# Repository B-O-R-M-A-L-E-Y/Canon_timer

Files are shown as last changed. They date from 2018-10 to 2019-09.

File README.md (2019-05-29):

# Canon_timer/Пульт Timelapse съёмки (для фотоаппартов Canon)
Можно настроить интервал между снимками, их количество и выдержку. Файлы печатной платы и схемы в папке timr_canon_pcb (проект в KiCAD). Исходный код в папке Src, имеется также иницализация CubeMX и проект в Keil. Применена библиотека HAL.
### Небольшая инструкция
 - При запуске фотоаппарат необходимо перевести в режим BULB.
 - Подключить пульт (разъем jack 2.5)
 - Настройка параметров осуществляется выбором соответствующего пункта меню. Затем нужно нажать на энкодер, вращением энкодера изменяется численное значение парметра. Для перехода к следующему значению нужно снова нажать на энкодер.
 - Для запуска перейти в пункт Start и нажать на энкодер. Для выхода из этого режима нажать на энкодер в течении 5 сек.

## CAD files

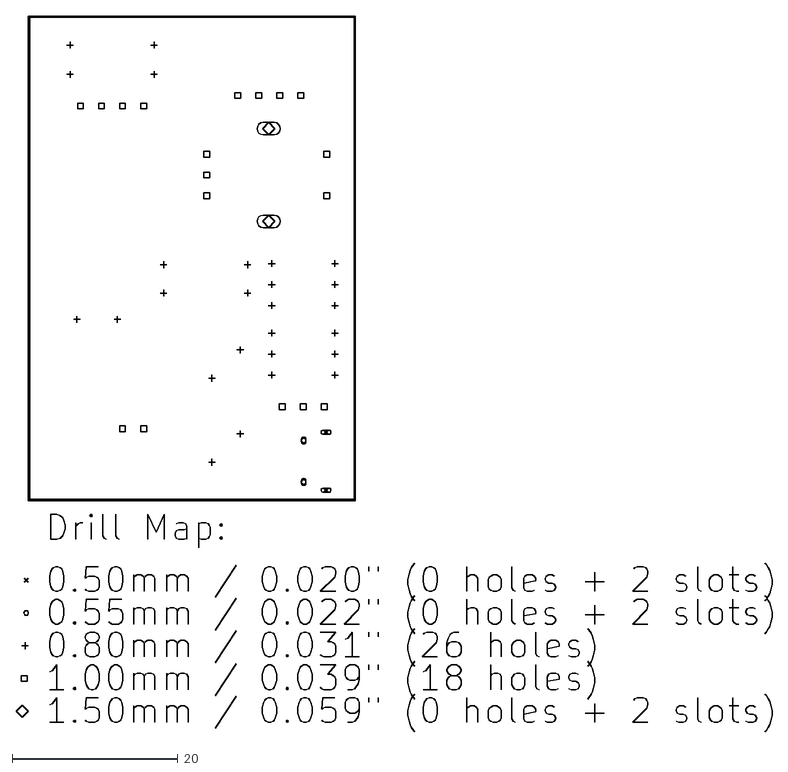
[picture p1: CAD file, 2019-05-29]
timr_canon_pcb/timer-drl_map.dxf
91.4 x 86.5

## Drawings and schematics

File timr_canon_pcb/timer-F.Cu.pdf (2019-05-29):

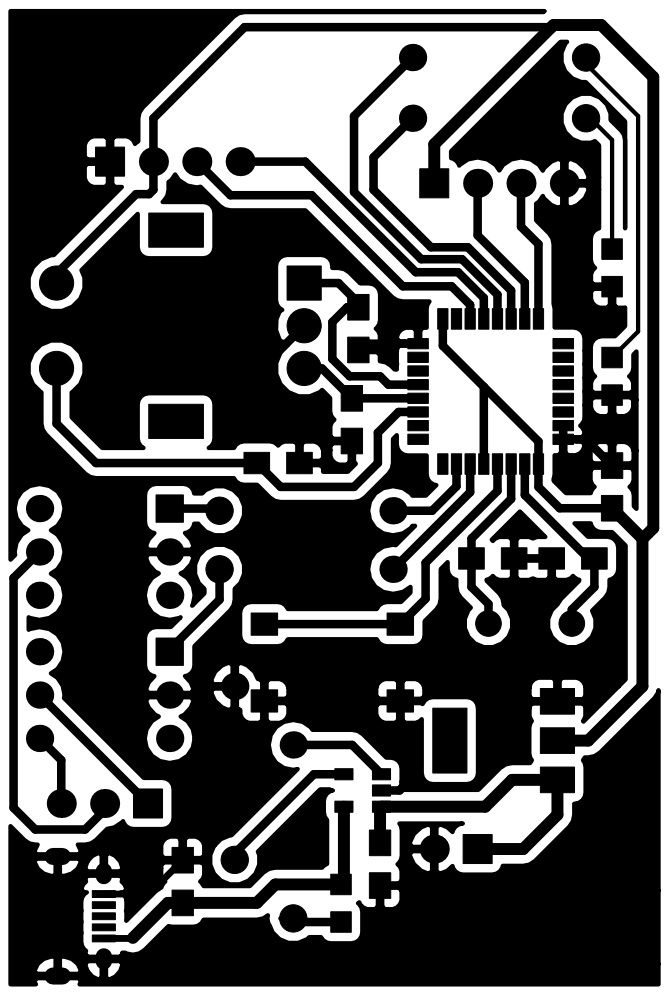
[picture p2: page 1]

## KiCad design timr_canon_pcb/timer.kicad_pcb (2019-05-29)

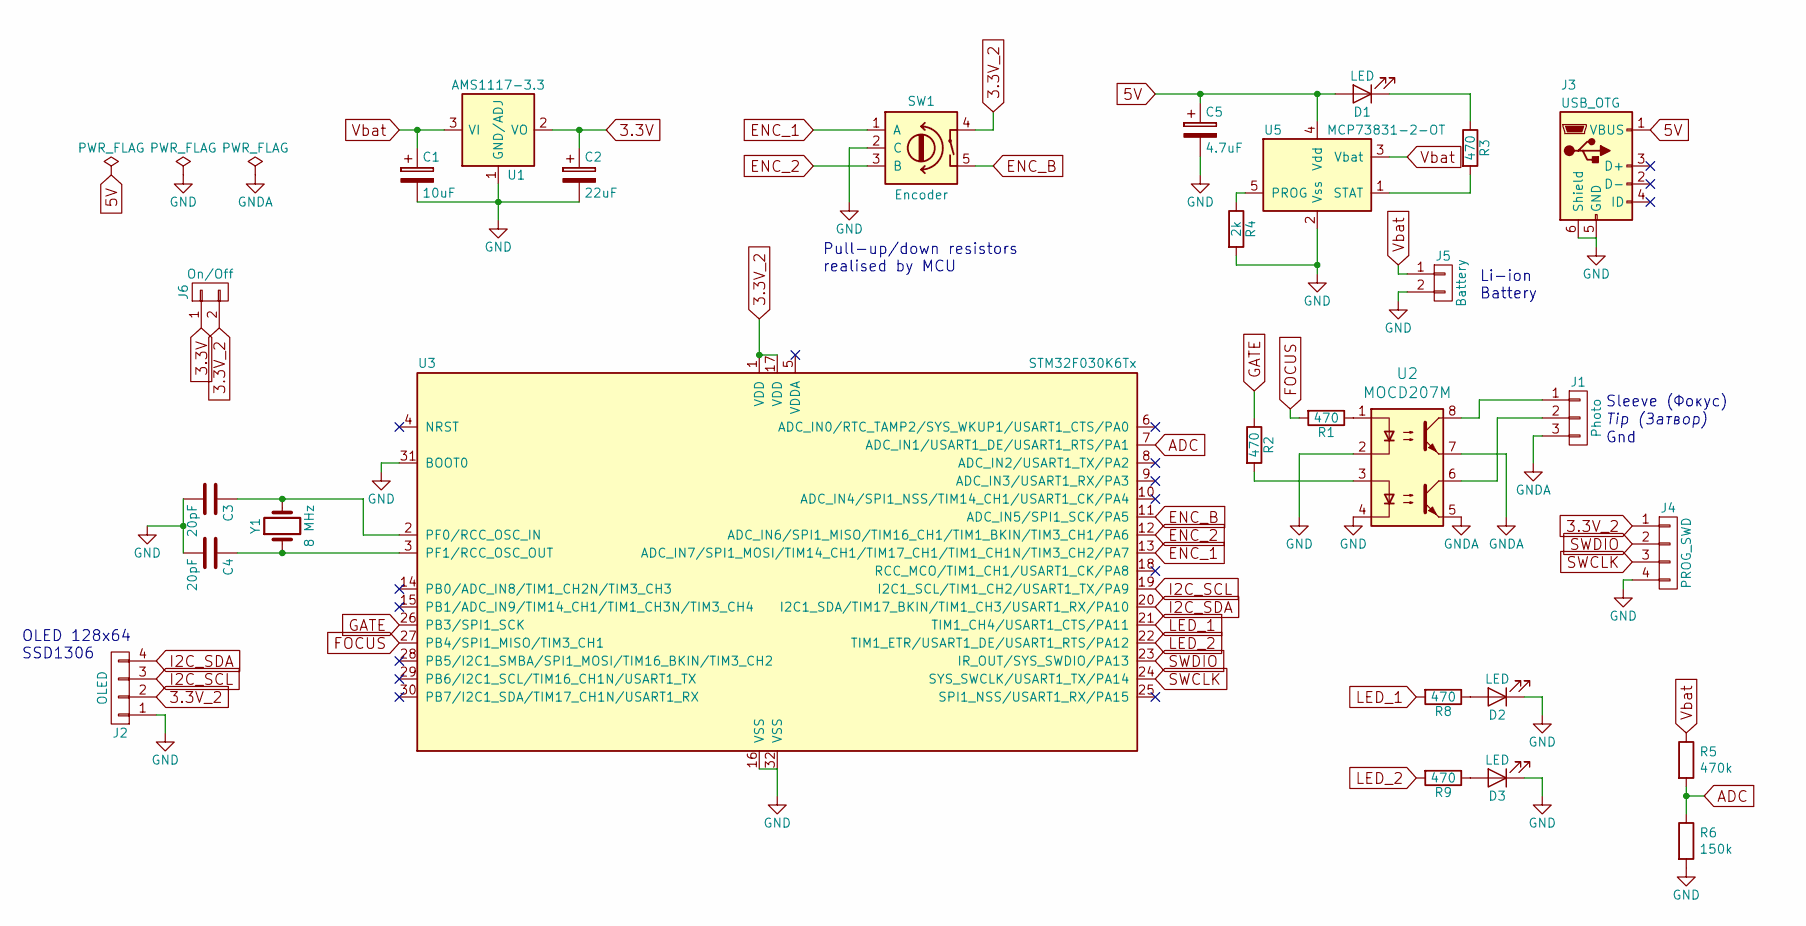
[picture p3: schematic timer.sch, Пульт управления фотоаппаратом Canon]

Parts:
C1: 10uF; C_0805_HandSoldering
C2: 22uF; C_0805_HandSoldering
C3, C4: 20pF; C_0805_HandSoldering
C5: 4.7uF; C_0805_HandSoldering
D1, D2, D3: LED; LED_0805
J1: Photo; Pin_Header_Straight_1x03_Pitch2.54mm
J2: OLED; Pin_Header_Straight_1x04_Pitch2.54mm
J3: USB_OTG; USB_Micro-B
J4: PROG_SWD; Pin_Header_Straight_1x04_Pitch2.54mm
J5: Battery; Pin_Header_Straight_1x02_Pitch2.54mm
J6: On/Off; Pin_Header_Straight_1x02_Pitch2.54mm
R1, R2, R3, R8, R9: 470; R_0805_2012Metric_Pad1.15x1.40mm_HandSolder
R4: 2k; R_0805_2012Metric_Pad1.15x1.40mm_HandSolder
R5: 470k; R_0805_2012Metric_Pad1.15x1.40mm_HandSolder
R6: 150k; R_0805_2012Metric_Pad1.15x1.40mm_HandSolder
SW1: Encoder; RotaryEncoder_Alps_EC11E-Switch_Vertical_H20mm
U1: AMS1117-3.3; SOT-223
U2: MOCD207M; SOIC-8_3.9x4.9mm_P1.27mm
U3: STM32F030K6Tx; LQFP-32_7x7mm_Pitch0.8mm
U5: MCP73831-2-OT; SOT-23-5
Y1: 8 MHz; Crystal_HC49-4H_Vertical

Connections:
3.3V: C2.1, J6.1, U1.2 (VO)
3.3V_2: J2.2, J4.1, J6.2, SW1.4, U3.1 (VDD), U3.17 (VDD)
5V: C5.1, D1.2 (A), J3.1 (VBUS), U5.4 (Vdd)
ADC: R5.2, R6.1, U3.7 (ADC_IN1/USART1_DE/USART1_RTS/PA1)
ENC_1: SW1.1 (A), U3.13 (ADC_IN7/SPI1_MOSI/TIM14_CH1/TIM17_CH1/T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)
ENC_2: SW1.3 (B), U3.12 (ADC_IN6/SPI1_MISO/TIM16_CH1/TIM1_BKIN/T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)
ENC_B: SW1.5, U3.11 (ADC_IN5/SPI1_SCK/PA5)
FOCUS: R1.2, U3.27 (PB4/SPI1_MISO/TIM3_CH1)
GATE: R2.1, U3.26 (PB3/SPI1_SCK)
GND: C1.2, C2.2, C3.2, C4.2, C5.2, D2.1 (K), D3.1 (K), J2.1, J3.5 (GND), J3.6 (Shield), J4.4, J5.2, R4.2, R6.2, SW1.2 (C), U1.1 (GND/ADJ), U2.2, U2.4, U3.16 (VSS), U3.31 (BOOT0), U3.32 (VSS), U5.2 (Vss)
GNDA: J1.3, U2.5, U2.7
I2C_SCL: J2.3, U3.19 (I2C1_SCL/TIM1_CH2/USART1_TX/PA9)
I2C_SDA: J2.4, U3.20 (I2C1_SDA/TIM17_BKIN/TIM1_CH3/USART1_RX/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)
LED_1: R8.2, U3.21 (TIM1_CH4/USART1_CTS/PA11)
LED_2: R9.2, U3.22 (TIM1_ETR/USART1_DE/USART1_RTS/PA12)
unnamed: C3.1, U3.2 (PF0/RCC_OSC_IN), Y1.2
unnamed: C4.1, U3.3 (PF1/RCC_OSC_OUT), Y1.1
unnamed: D1.1 (K), R3.1
unnamed: D2.2 (A), R8.1
unnamed: D3.2 (A), R9.1
unnamed: J1.1, U2.8
unnamed: J1.2, U2.6
unnamed: R1.1, U2.1
unnamed: R2.2, U2.3
unnamed: R3.2, U5.1 (STAT)
unnamed: R4.1, U5.5 (PROG)
SWCLK: J4.3, U3.24 (SYS_SWCLK/USART1_TX/PA14)
SWDIO: J4.2, U3.23 (IR_OUT/SYS_SWDIO/PA13)
Vbat: C1.1, J5.1, R5.1, U1.3 (VI), U5.3 (Vbat)

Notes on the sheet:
Tip (Затвор)
Sleeve (Фокус)
Gnd
OLED 128x64 SSD1306
Li-ion Battery
Pull-up/down resistors realised by MCU

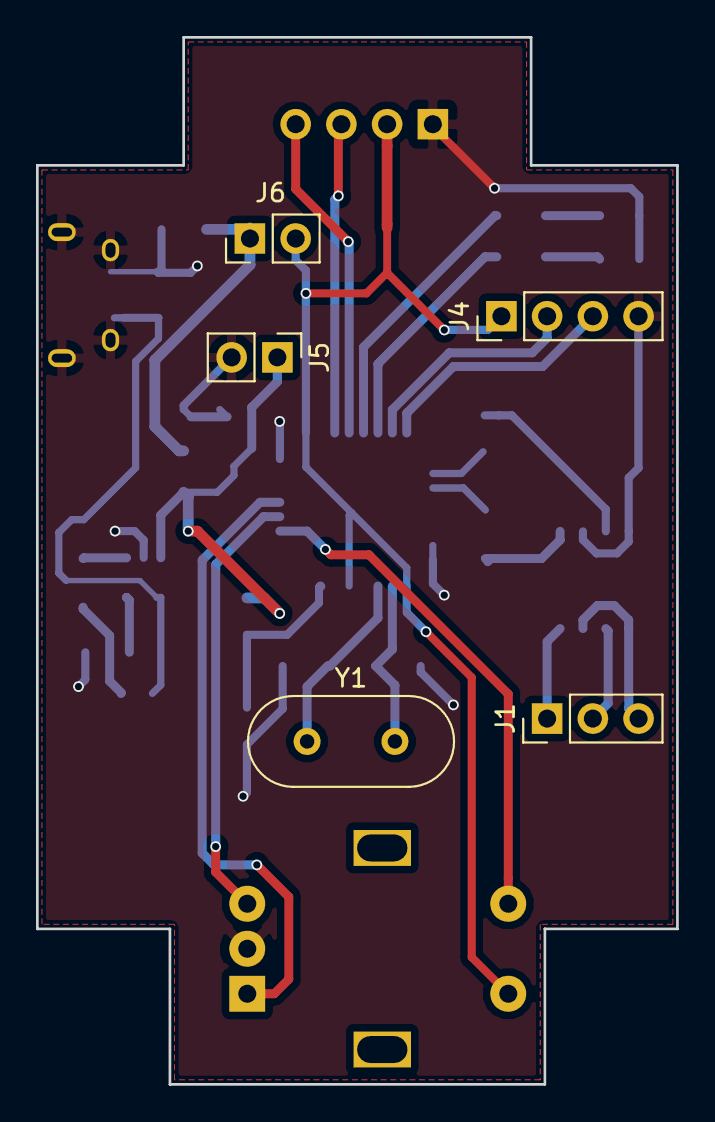
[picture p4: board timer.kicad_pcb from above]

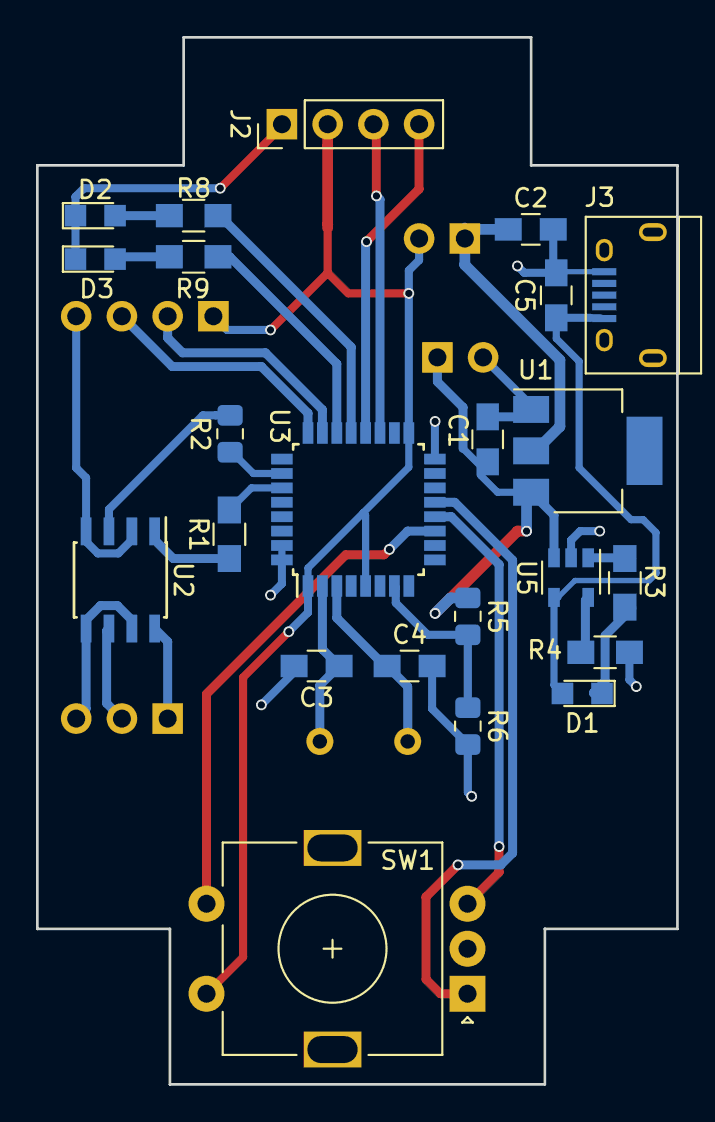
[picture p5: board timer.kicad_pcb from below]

Board: 2 copper layers, 35.6 x 58.2 mm, 28 parts (23 on the bottom side), 29 nets.

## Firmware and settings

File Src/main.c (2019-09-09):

/**
  ******************************************************************************
  * @file           : main.c
  * @brief          : Main program body
  ******************************************************************************
  ** This notice applies to any and all portions of this file
  * that are not between comment pairs USER CODE BEGIN and
  * USER CODE END. Other portions of this file, whether
  * inserted by the user or by software development tools
  * are owned by their respective copyright owners.
  *
  * COPYRIGHT(c) 2018 STMicroelectronics
  *
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
  ******************************************************************************
  */
/* Includes ------------------------------------------------------------------*/
#include "main.h"
#include "stm32f0xx_hal.h"

/* USER CODE BEGIN Includes */
#include "ssd1306.h"
#include "stdlib.h"
#include "string.h"
/* USER CODE END Includes */

I2C_HandleTypeDef hi2c1;

IWDG_HandleTypeDef hiwdg;

TIM_HandleTypeDef htim3;
TIM_HandleTypeDef htim14;
TIM_HandleTypeDef htim16;
TIM_HandleTypeDef htim17;

ADC_HandleTypeDef hadc;

/* USER CODE BEGIN PV */
/* --------------------------- Private variables -----------------------------*/

AUTOMATE_STATES current_state = menu_navigation;
CURSOR_STATES current_cursor = exposition;

// Exposition parameters
uint16_t set_exp_minutes = 0, set_exp_sec = 3;
uint16_t tmp_exp_minutes, tmp_exp_sec;
// Number of shots
uint16_t set_num_shots = 3, tmp_num_shots;
// Interval paramters
uint16_t set_int_minutes = 0, set_int_sec = 5;
uint16_t tmp_int_minutes, tmp_int_sec;



uint8_t update_screen_flag = 0, gate_flag = 0, exiting_run = 0;

uint32_t seconds_counter = 0;

char *Menu_Items[]={"Exp:               ",
                    "Num:               ",
                    "Int:               ",
                    "Start              "};

char buffer[5];
/* USER CODE END PV */

void SystemClock_Config(void);
static void MX_GPIO_Init(void);
static void MX_I2C1_Init(void);
static void MX_TIM3_Init(void);
//static void MX_IWDG_Init(void);
static void MX_TIM14_Init(void);
static void MX_TIM16_Init(void);
static void MX_TIM17_Init(void);
static void MX_ADC_Init(void);

/* USER CODE BEGIN PFP */
/* ---------------------------- Private function prototypes ------------------*/

void reverse(char s[]);
void itoa(int n, char s[]);

void Menu(void);
void Convert_time(uint16_t* minutes, uint16_t* seconds);

/* USER CODE END PFP */

/**
  * @brief  The application entry point.
  *
  * @retval None
  */
int main(void)
{
  /* MCU Configuration----------------------------------------------------------*/

  /* Reset of all peripherals, Initializes the Flash interface and the Systick. */
  HAL_Init();

  /* Configure the system clock */
  SystemClock_Config();

  /* Initialize all configured peripherals */
  MX_GPIO_Init();
	MX_ADC_Init();
	HAL_Delay(300);
  MX_I2C1_Init();
  MX_TIM3_Init();
  //MX_IWDG_Init();
  MX_TIM14_Init();
  MX_TIM16_Init();
  MX_TIM17_Init();
  /* USER CODE BEGIN 2 */
	current_state = menu_navigation;
  HAL_TIM_Encoder_Start(&htim3, TIM_CHANNEL_ALL);
  HAL_NVIC_SetPriority(TIM3_IRQn, 0, 0);
  HAL_NVIC_EnableIRQ(TIM3_IRQn);
  HAL_TIM_Base_Start_IT(&htim3);


  // Seconds Counter startup duty
  HAL_TIM_Base_Start_IT(&htim14);
  HAL_TIM_Base_Stop_IT(&htim14);
  HAL_TIM_Base_Start_IT(&htim16);
	HAL_ADC_Start(&hadc);

  HAL_TIM_Base_Start_IT(&htim17);

  HAL_GPIO_WritePin(GPIOA, LED_RED_PIN, GPIO_PIN_RESET);
  ssd1306_Init();
  current_cursor = exposition;
  /* USER CODE END 2 */

  /* Infinite loop */
  /* USER CODE BEGIN WHILE */
  while (1)
  {
  /* USER CODE END WHILE */

  /* USER CODE BEGIN 3 */
    //HAL_IWDG_Refresh(&hiwdg);

    if(__HAL_RCC_GET_SYSCLK_SOURCE() == RCC_SYSCLKSOURCE_STATUS_PLLCLK) HAL_GPIO_WritePin(GPIOA, LED_GREEN_PIN, GPIO_PIN_SET);
    else HAL_GPIO_WritePin(GPIOA, LED_GREEN_PIN, GPIO_PIN_RESET);

    if (update_screen_flag)
    {
      ssd1306_Fill(Black);
      ssd1306_UpdateScreen();
      update_screen_flag = 0;
    }
		
    if (seconds_counter > STOP_TIME_SEC) //if more than 10 s need to stop
    {
			/*
      // Entering STOP Mode Procedure
      seconds_counter = 0;

      GPIO_InitTypeDef GPIO_InitStruct;
      

      ssd1306_WriteCommand(0xAE);       // OLED Off

      GPIO_InitStruct.Pin = ENC_BUTTON_PIN;
      GPIO_InitStruct.Mode = GPIO_MODE_EVT_RISING_FALLING;
      GPIO_InitStruct.Pull = GPIO_PULLDOWN;
      GPIO_InitStruct.Speed = GPIO_SPEED_FREQ_LOW;
      HAL_GPIO_Init(GPIOA, &GPIO_InitStruct);

      HAL_NVIC_SetPriority(EXTI4_15_IRQn, 0, 0);
      HAL_NVIC_EnableIRQ(EXTI4_15_IRQn);

      HAL_GPIO_WritePin(GPIOA, LED_GREEN_PIN|LED_RED_PIN, GPIO_PIN_RESET);
      HAL_GPIO_WritePin(GPIOB, GATE_PIN|FOCUS_PIN, GPIO_PIN_RESET);

      HAL_PWR_EnterSTOPMode(PWR_LOWPOWERREGULATOR_ON, PWR_STOPENTRY_WFE);

      // Exit from STOP Mode procedure
      SystemClock_Config();
      ssd1306_WriteCommand(0xAF);      // OLED On

      GPIO_InitStruct.Pin = ENC_BUTTON_PIN;
      GPIO_InitStruct.Mode = GPIO_MODE_INPUT;
      GPIO_InitStruct.Pull = GPIO_PULLDOWN;
      HAL_GPIO_Init(GPIOA, &GPIO_InitStruct);
      
      // Need Delay to avoid going in interrupt
      HAL_NVIC_DisableIRQ(TIM3_IRQn);
      HAL_Delay(800);
      HAL_NVIC_EnableIRQ(TIM3_IRQn);
      
      current_state = menu_navigation;
			*/
			
    }

    Menu();
    
    if (current_state == running_timer || current_state == running_interval)
    {
      if(gate_flag)
      {
        // Reset Gate & Focus
        HAL_GPIO_WritePin(GPIOB, FOCUS_PIN|GATE_PIN, GPIO_PIN_RESET);
        HAL_TIM_Base_Stop_IT(&htim14);
        HAL_Delay(500);
        __HAL_TIM_SET_COUNTER(&htim14, 0);
        HAL_TIM_Base_Start_IT(&htim14);
        gate_flag = 0;
        // If not last shot, go to Interval state
        if(tmp_num_shots != 0)
        {
          tmp_int_minutes = set_int_minutes;
          tmp_int_sec = set_int_sec;
          tmp_exp_minutes = set_exp_minutes;
          tmp_exp_sec = set_exp_sec;
          current_state = running_interval;
          HAL_GPIO_WritePin(GPIOA, LED_RED_PIN,GPIO_PIN_RESET); // 1s LED Off
        }
        else
        {
          HAL_TIM_Base_Stop_IT(&htim14);
          __HAL_TIM_SET_COUNTER(&htim14, 0);
          HAL_GPIO_WritePin(GPIOA, LED_RED_PIN,GPIO_PIN_RESET); // 1s LED Off
          tmp_exp_minutes = set_exp_minutes;
          tmp_exp_sec = set_exp_sec;
          current_state = menu_navigation;
          update_screen_flag = 1;
        }
      }
    }
      
    if (exiting_run)
    {
      HAL_TIM_Base_Stop_IT(&htim16);
      HAL_Delay(1000);
      exiting_run = 0;
      HAL_TIM_Base_Start_IT(&htim16);
      HAL_GPIO_WritePin(GPIOB, FOCUS_PIN|GATE_PIN, GPIO_PIN_RESET);
    }   
  }
  /* USER CODE END 3 */

}

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
/* USER CODE BEGIN 4 */

// Reverse string
void reverse(char s[])
{
  int i, j;
  char c;

  for (i = 0, j = strlen(s)-1; i<j; i++, j--)
  {
    c = s[i];
    s[i] = s[j];
    s[j] = c;
  }
}

// Convert number n into char[] s
void itoa(int n, char s[])
{
  int i, sign;

  if ((sign = n) < 0)  /* записываем знак */
    n = -n;          /* делаем n положительным числом */
  i = 0;
  do {       /* генерируем цифры в обратном порядке */
    s[i++] = n % 10 + '0';   /* берем следующую цифру */
  } while ((n /= 10) > 0);     /* удаляем */
  if (sign < 0)
    s[i++] = '-';
  s[i] = '\0';
  reverse(s);
}

// Generate and update menu
void Menu(void)
{
  if (current_state != running_timer && current_state != running_interval)
  {
    for (int i=0; i<NUMBER_OF_MENU_ITEMS; i++)
    {
      ssd1306_SetCursor(0, i*FONT_HEIGHT);
      if(current_cursor == i) ssd1306_WriteString("->", Font_7x10, White);
      ssd1306_WriteString(Menu_Items[i], Font_7x10, White);
      switch (i)
      {
        case exposition:
          ssd1306_SetCursor(FONT_WIDTH*INDENT, i*FONT_HEIGHT);
          itoa(set_exp_minutes, buffer);
          ssd1306_WriteString(buffer, Font_7x10, White);
          ssd1306_WriteString("`  ", Font_7x10, White);
          itoa(set_exp_sec, buffer);
          ssd1306_WriteString(buffer, Font_7x10, White);
          ssd1306_WriteString("``", Font_7x10, White);
          break;
        case number:
          ssd1306_SetCursor(FONT_WIDTH*INDENT, i*FONT_HEIGHT);
          itoa(set_num_shots, buffer);
          ssd1306_WriteString(buffer, Font_7x10, White);
          break;
        case interval:
          ssd1306_SetCursor(FONT_WIDTH*INDENT, i*FONT_HEIGHT);
          itoa(set_int_minutes, buffer);
          ssd1306_WriteString(buffer, Font_7x10, White);
          ssd1306_WriteString("`  ", Font_7x10, White);
          itoa(set_int_sec, buffer);
          ssd1306_WriteString(buffer, Font_7x10, White);
          ssd1306_WriteString("``", Font_7x10, White);
          break;
        case start:
          break;
      }
    }
		/*
		itoa(p, buffer);
		ssd1306_SetCursor(0, 40);
		ssd1306_WriteString("Charge:    %", Font_7x10, White);
		ssd1306_SetCursor(8*FONT_WIDTH, 40);
		ssd1306_WriteString(buffer, Font_7x10, White);
		*/
  }
  else
  {
    for (int i=0; i<NUMBER_OF_MENU_ITEMS-1; i++)
    {
      ssd1306_SetCursor(0, i*FONT_HEIGHT);
      ssd1306_WriteString(Menu_Items[i], Font_7x10, White);
      switch (i)
      {
        case exposition:
          ssd1306_SetCursor(FONT_WIDTH*INDENT, i*FONT_HEIGHT);
          itoa(tmp_exp_minutes, buffer);
          ssd1306_WriteString(buffer, Font_7x10, White);
          ssd1306_WriteString("`  ", Font_7x10, White);
          itoa(tmp_exp_sec, buffer);
          ssd1306_WriteString(buffer, Font_7x10, White);
          ssd1306_WriteString("``", Font_7x10, White);
          break;
        case number:
          ssd1306_SetCursor(FONT_WIDTH*INDENT, i*FONT_HEIGHT);
          itoa(tmp_num_shots, buffer);
          ssd1306_WriteString(buffer, Font_7x10, White);
          break;
        case interval:
          ssd1306_SetCursor(FONT_WIDTH*INDENT, i*FONT_HEIGHT);
          itoa(tmp_int_minutes, buffer);
          ssd1306_WriteString(buffer, Font_7x10, White);
          ssd1306_WriteString("`  ", Font_7x10, White);
          itoa(tmp_int_sec, buffer);
          ssd1306_WriteString(buffer, Font_7x10, White);
          ssd1306_WriteString("``", Font_7x10, White);
          break;
        case start:
          break;
      }
    }
		/*
		itoa(p, buffer);
		ssd1306_SetCursor(0, 30);
		ssd1306_WriteString("Charge:    %", Font_7x10, White);
		ssd1306_SetCursor(8*FONT_WIDTH, 30);
		ssd1306_WriteString(buffer, Font_7x10, White);
		*/
    ssd1306_SetCursor(0, NUMBER_OF_MENU_ITEMS*FONT_HEIGHT);
    ssd1306_WriteString("     Running      ", Font_7x10, White);
  }
  ssd1306_UpdateScreen();
}


void Convert_time(uint16_t* minutes, uint16_t* seconds)
{
  if (*seconds >= 60)
  {
    uint16_t tmp_min;
    tmp_min = (*seconds)/60;
    *minutes = *minutes+tmp_min;
    *seconds = *seconds-tmp_min*60;
  }
}

/* USER CODE END 4 */
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


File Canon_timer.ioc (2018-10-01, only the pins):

Mcu.UserName=STM32F030K6Tx
PA0.Signal=GPIO_Output
PA1.Signal=GPIO_Output
PA10.Signal=I2C1_SDA
PA11.Signal=GPIO_Output
PA12.Signal=GPIO_Output
PA13.Signal=SYS_SWDIO
PA14.Signal=SYS_SWCLK
PA5.Signal=GPIO_Input
PA6.Signal=S_TIM3_CH1
PA7.Signal=S_TIM3_CH2
PA9.Signal=I2C1_SCL
PF0-OSC_IN.Signal=RCC_OSC_IN
PF1-OSC_OUT.Signal=RCC_OSC_OUT

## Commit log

2018-10-01 Lower current consumption
    Added switching off OLED before going to sleep. Also ssd1306.h now has public WriteCommand function (it was static)
2018-10-08 Exit by holding button for 3s
2018-10-27 could exit from running by holding button
2019-05-29 add pcb & schematics
    [pcb_old-4n25-v2.kicad_pcb, pcd_old-4n25-v1.kicad_pcb, timer-2019-05-12-21-28-26.sch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]

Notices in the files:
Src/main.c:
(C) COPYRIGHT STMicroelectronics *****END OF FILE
